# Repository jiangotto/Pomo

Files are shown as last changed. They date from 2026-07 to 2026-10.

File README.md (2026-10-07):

# Pomo

[English](README.md) | [简体中文](README_CN.md)

An open-source FPGA controller board that converts a 2-lane MIPI DSI video stream into source/gate timing for parallel-interface electrophoretic displays (EPDs).

## Overview

Pomo accepts ordinary RGB888 video from a Linux SBC or another MIPI DSI host and converts it into the waveform-driven pixel states and scanning signals required by a parallel-interface E-Ink display. Both generations use a Gowin GW1NSR-4C FPGA and a HyperRAM framebuffer.

## Versions

Pomo currently has two matching hardware and firmware generations:

| | V1 | V2 |
|---|---|---|
| Status | Original version, retained for existing boards | Current version and active development target |
| EPD Source bus | 8-bit, four 2-bit pixels per SDCLK | 16-bit, eight 2-bit pixels per SDCLK |
| PMIC | TPS65185 | SY7636A by default; TPS65185 selectable in firmware |
| Control pins | FPGA controls GDOE, SDOE, PMIC WAKEUP and VCOM control | GDOE/SDOE and PMIC auxiliary control are handled by hardware, freeing pins for D8–D15 |
| Project paths | `Firmware/V1`, `Hardware/V1`, `Case/V1` | `Firmware/V2`, `Hardware/V2`, `Case/V2` |

V1 and V2 bitstreams are not interchangeable because their EPD bus width, pin assignment, and PMIC control differ. Choose one generation and use its matching firmware, hardware, and mechanical files.

## V2

<div align="center">
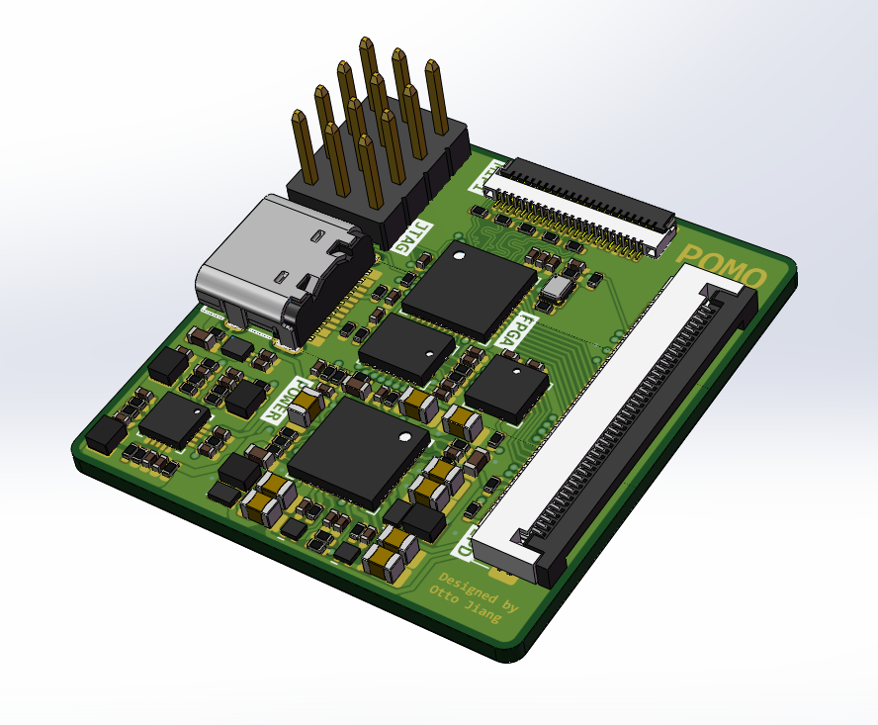
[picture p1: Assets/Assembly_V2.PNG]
Pomo V2 assembly
  
</div>

V2 combines the FPGA, HyperRAM, EPD power-management circuit, and 16-bit parallel Source interface on one board. It is the recommended starting point for new builds and the main focus of the documentation below.

The MIPI input has been tested with Luckfox and Waveshare development boards. Depending on the host connector, a reverse FPC cable may be required.

## V2 highlights

- 2-lane MIPI DSI RGB888 video input
- Gowin MIPI receiver configured for two lanes in 1:16 mode
- Dynamically measured MIPI byte clock and runtime PLL output-divider selection
- HyperRAM framebuffer for current and target pixel states, with optional packed 12-bit state storage
- 16-bit EPD source bus: eight 2-bit drive pixels are loaded per SDCLK
- Source and gate timing generation for parallel-interface EPD panels
- Selectable SY7636A or TPS65185 PMIC control; V2 defaults to SY7636A
- Optional `2W × H` to `W × 2H` pixel reorder for ET073TC1-style panel mappings
- Built-in static and animated test patterns that can replace the MIPI source
- Blue-noise dithering and multiple waveform/update modes
- FIFO, framebuffer and frame-level diagnostic counters
- Wider horizontal timing counters for high-resolution panels such as 1216 × 684
- Runtime display-mode switching through an in-stream MIPI DSI generic short packet
- Runtime PMIC power control with fail-safe EPD output clamping on MIPI PLL loss

The current 1216 × 684 configuration has been tested at up to 85 Hz. This result depends on a short, well-routed FPC connection and correctly tuned D-PHY input delay; it is not a guaranteed limit for every host, cable, or PCB.

## Data path

```text
2-lane MIPI DSI
      │
      ▼
Gowin D-PHY RX ──► DSI packet decode ──► RGB888 byte-to-pixel conversion
                                              │
                         optional pixel reorder / internal test source
                                              │
                                              ▼
                               grayscale + dithering + waveform engine
                                              │
                                              ▼
                                      HyperRAM framebuffer
                                              │
                                              ▼
                           16-bit Source timing + Gate timing ──► EPD
```

The firmware is derived from the [Caster EPDC design](https://gitlab.com/zephray/Glider) by Wenting Zhang. The original Spartan-6 implementation was ported to Gowin, adapted to a HyperRAM framebuffer, and extended for MIPI input and standalone panel driving.

## Hardware

V2 exposes a 16-bit EPD data bus together with `SDCLK`, `SDLE`, `SDCE`, `GDCLK`, and `GDSP`. `GDOE` and `SDOE` are handled by pull-ups on the V2 board rather than FPGA pins. PMIC WAKEUP/VCOM control is likewise handled by the V2 hardware, leaving FPGA pins available for `EPD_D8` through `EPD_D15`.

The Altium source, schematic PDF, PCB layout, BOM, and pick-and-place files are in [`Hardware/V2`](Hardware/V2). Do not use V1 firmware on V2 hardware or V2 firmware on V1 hardware: their EPD bus width, pin assignment, and PMIC control differ.

### JTAG / I/O header

<div align="center">
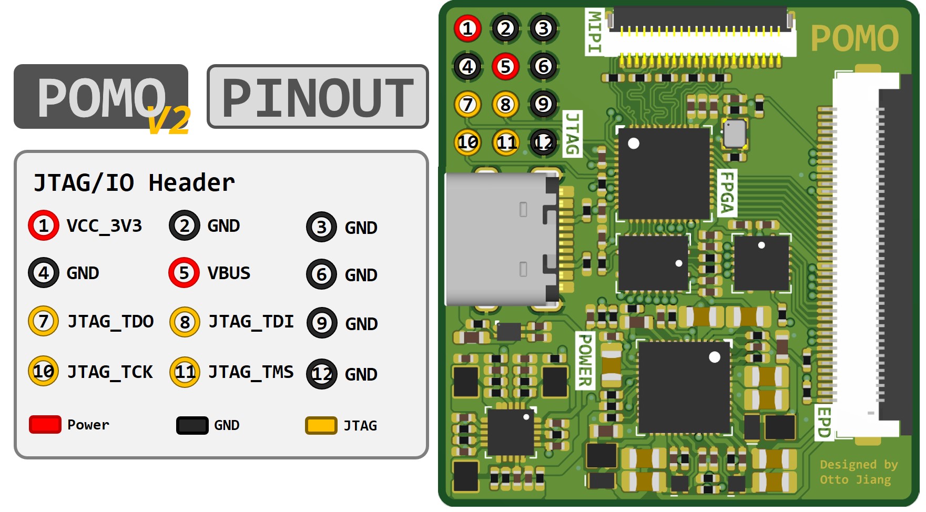
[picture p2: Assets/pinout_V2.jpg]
Pomo V2 JTAG and I/O header pinout
  
</div>

The header provides 3.3 V, VBUS, ground, and the four JTAG signals. Check orientation against the pin-1 marker before connecting a programmer.

## Example

<div align="center">
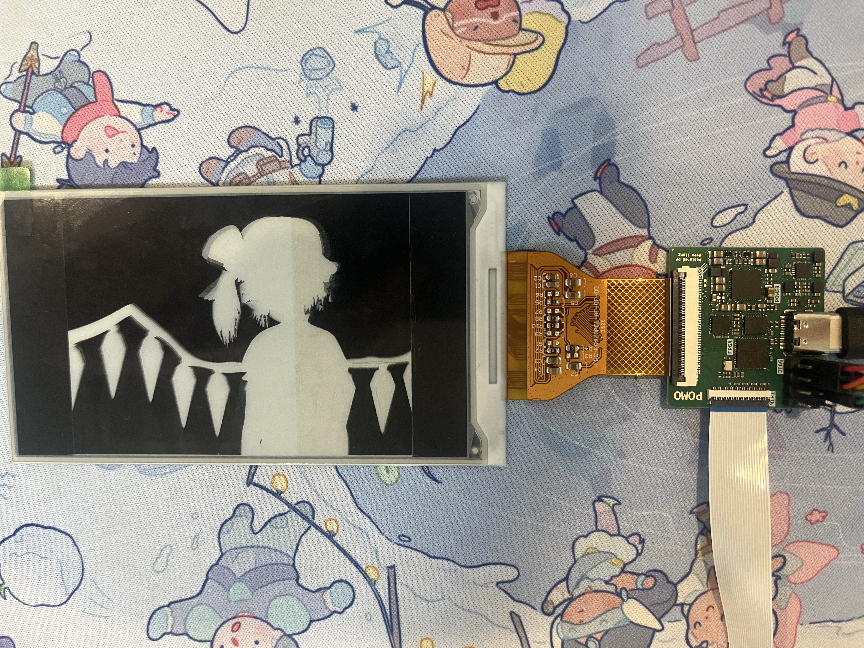
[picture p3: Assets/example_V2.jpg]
Pomo V2 driving a parallel-interface E-Ink display
  
</div>

<div align="center">
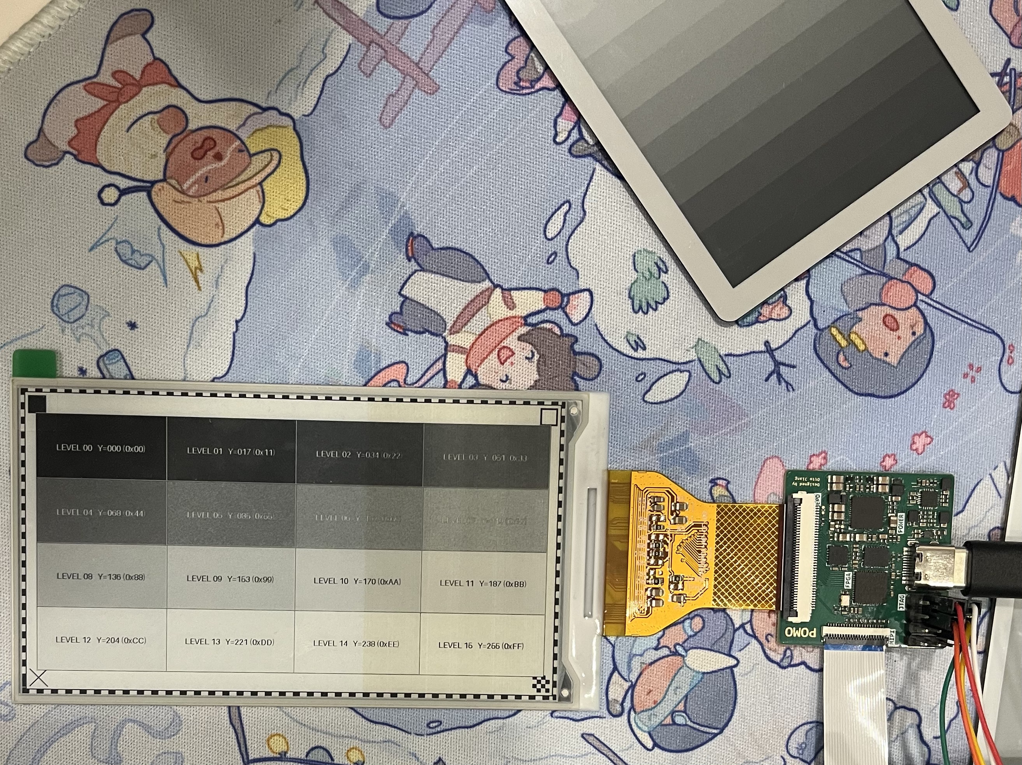
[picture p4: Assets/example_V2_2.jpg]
Pomo V2 displaying a 16-level grayscale test pattern
  
</div>

## Building the V2 firmware

1. Open [`Firmware/V2/Pomo.gprj`](Firmware/V2/Pomo.gprj) in Gowin EDA V1.9.12.
2. Edit [`Firmware/V2/src/defines.vh`](Firmware/V2/src/defines.vh) for the target PMIC, panel timing, source width, waveform mode, and VCOM voltage.
3. Verify that both generated MIPI IPs use two lanes and the same **1:16** D-PHY mode. The checked-in receiver configuration uses byte/lane alignment and an input delay of 46 on both data lanes; retune this value for the actual board and cable.
4. Run **Synthesis → Place & Route → Generate Bitstream** and confirm that both setup and hold timing pass.
5. Program the FPGA through the JTAG header.

The checked-in project uses Gowin-generated MIPI D-PHY, protocol-decoder, PLL, framebuffer and FIFO modules. The generated IP configuration and source under `Firmware/V2/src` are tracked because regenerating an IP with different GUI settings changes hardware behavior. Disposable synthesis, simulation and implementation products are excluded from version control.

## V2 firmware configuration

The main build-time switches are defined in [`Firmware/V2/src/defines.vh`](Firmware/V2/src/defines.vh):

| Option | Purpose |
|---|---|
| `PMIC_SY7636A` | Keep defined for SY7636A; comment it out for TPS65185 |
| `EPD_OUTPUT_WIDTH` | Select the EPD source output width; V2 hardware uses 16 |
| `EPD_INTERNAL_TEST` | Replace the external MIPI stream with the internal video generator |
| `EPD_TEST_PATTERN_MODE` | Select one of the static or animated internal test patterns |
| `EPD_TEST_PATTERN_FPS` | Set the frame rate of the internal test source |
| `EPD_PIXEL_REORDER` | Convert a logical `2W × H` input into a physical `W × 2H` panel raster |
| `EPD_DEFAULT_MODE` | Select the power-on display mode: `8` MONO, `A` MONO + blue noise, `B` GREY, or `C` AUTO LUT |
| `EPD_STATE_12BIT` | Pack four 12-bit pixel states into three 16-bit VFB samples, reducing framebuffer traffic by 25% compared with one 16-bit state per pixel |
| `DEFAULT_*` | Set the expected MIPI active area, sync and porch timing |
| `EPD_STV_TO_G1_CKV` | Set the panel-specific CKV shift distance from STV sampling through the shift immediately before G1 |
| `VCOM_VOL` | Set panel VCOM in millivolts; always verify against the panel datasheet |
| `CLEAR_FRAMES` | Set the final zero-based index of the startup clear sequence |
| `LUT_FRAMES` | Set the waveform LUT length |

The current example configuration uses a 1216 × 684 MIPI input, 16-bit source output, packed 12-bit framebuffer states, SY7636A, MONO startup mode, and pixel reorder disabled. The internal test source runs at 85 Hz. This is an example for the panel currently under development, not a universal setting.

#### Why `EPD_STATE_12BIT` exists

This option changes only the representation stored through the framebuffer; it does **not** change the RGB888 MIPI input into 12-bit color, reduce the EPD output bus width, or reduce the available display modes or grayscale levels.

The processing pipeline's original 16-bit per-pixel state contains a 4-bit display-mode field plus 12 bits of actual per-pixel state. Because the display mode is global and identical for every pixel, repeatedly storing that upper nibble wastes HyperRAM bandwidth. With `EPD_STATE_12BIT` enabled, Pomo removes the repeated mode nibble, packs four 12-bit states into three samples of the existing 16-bit VFB, and restores the current global mode after reading:

```text
original storage: 4 pixels × 16 bits = 64 bits
packed storage:   4 pixels × 12 bits = 48 bits
```

This reduces both framebuffer write and read traffic from 2 bytes to 1.5 bytes per pixel—a 25% reduction—which provides the memory-bandwidth margin needed for high input refresh rates such as the currently tested 85 Hz mode.

- Leave `EPD_STATE_12BIT` defined for the bandwidth-optimized path.
- Comment it out to use the original one-16-bit-state-per-pixel path for comparison, debugging, or an incompatible raster width.
- The framebuffer-side active width (`EPD_HACT` after optional pixel reorder) must be divisible by four, because packing restarts at every line and each group contains four pixels. The current width of 1216 satisfies this requirement. With `EPD_PIXEL_REORDER`, the resulting physical width—not only `DEFAULT_HACT`—must satisfy it.
- No 24-bit VFB IP is required; the optimization deliberately retains the proven 16-bit VFB configuration.

### MIPI receiver configuration and signal integrity

The two generated MIPI IPs must use matching settings:

- **MIPI RX Advance:** two data lanes, 1:16 D-PHY mode, byte alignment enabled, lane alignment enabled.
- **MIPI DSI/CSI-2 Receiver:** DSI interface, two RX lanes, 1:16 D-PHY mode, I/O insertion disabled.

At high lane rates, a syntactically correct design may still show split frames, snow, or corrupted pixels when the sampling eye is too narrow. Use the shortest practical FPC, keep both lanes well matched, and tune `HS Data0/1 IO Delay Value` using repeatable test images. The current value of 46 is a result for the tested Pomo/RK3506 connection, not a panel parameter. This GW1NSR-4C configuration does not perform automatic IODELAY training, so a different host, PCB, or cable may require a new value.

For RGB888 in 1:16 D-PHY mode, with `L` active data lanes:

```text
pixel clock     = H_TOTAL × V_TOTAL × refresh rate
1:16 word clock = pixel clock × 3 / (2 × L)
D-PHY clock     = pixel clock × 12 / L
```

Set `MIPI_RX_LANES` in `defines.vh` and enable the matching `Pomo_1lane.sdc` or `Pomo_2lane.sdc` in `Firmware/V2/Pomo.gprj`. The checked-in project defaults to two lanes. When changing resolution or maximum refresh rate, update that lane's clock constraints along with the video timing. Do not hide failures by removing the HS, word, pixel, or HyperRAM constraints. The 4-lane implementation and its disabled SDC are retained for development, but 4-lane is not a supported build: hardware validation has failed and the current implementation nearly exhausts FPGA resources.

### Runtime display and power control

The display mode and panel power request can be changed without rebuilding the FPGA by sending a MIPI DSI **Generic Short Write, 2 parameters** packet (`DT = 0x23`):

| Payload | Mode |
|---|---|
| `50 08` | MONO |
| `50 0A` | MONO + blue noise |
| `50 0B` | GREY |
| `50 0C` | AUTO LUT |
| `51 00` | Clamp the EPD interface and place the PMIC in standby |
| `51 01` | Request panel power-on; the normal initialization clear runs again |
| `52 A5` | Restart the initialization clear without cycling panel power, then return to the requested display mode |

With a Rockchip `panel-simple-dsi` driver that supports the `panel-init-sequence` format, the startup mode can be selected in the panel device-tree node. For example, this sequence has been verified to select AUTO LUT before video begins:

```dts
panel-init-sequence = [
    23 0A 02 50 0C
];
```

`23` is the DSI data type for Generic Short Write with two parameters, `0A` is a 10 ms delay after transmission, `02` is the payload length, and `50 0C` is Pomo's display-mode command. Startup commands are received over LPDT, so they do not have to wait for HS video or IODELAY training. To select another mode, replace the final byte with `08`, `0A`, or `0B` from the table above. `EPD_DEFAULT_MODE` remains the fallback when no mode command is received. Other hosts or panel drivers may use a different device-tree command format; do not assume this five-byte wrapper is universal.

During active video, insert commands as HS short packets while the DSI controller remains in video mode. Do **not** switch the DesignWare DSI host's `MODE_CFG` to command mode and back: doing so restarts the video packetizer at an arbitrary horizontal phase and can shift the image. A Linux kernel panel/bridge driver should normally issue the packet through `mipi_dsi_generic_write()`. If a diagnostic register-level tool is used, it must leave `MODE_CFG`, `VID_MODE_CFG`, and the running video timing unchanged and only enqueue the HS short packet through the generic-command FIFO.

The power request defaults to ON, but in the normal MIPI build the physical panel rails remain off until the dynamically configured pixel PLL is ready and locked. `51 00` first clamps the complete EPD interface to its inactive levels, then places the selected PMIC in standby. For SY7636A this clears `ON_OFF` while keeping `EN` high so I2C remains available; for TPS65185 it lowers `PWRUP`. After `51 01`, Pomo waits for the PMIC and HyperRAM, returns to `INIT_IDLE`, and performs `INIT_CLEARING` before normal updates resume. `EPD_INTERNAL_TEST` does not require a MIPI lock and powers the PMIC from the internal test path.

`52 A5` leaves the PMIC and MIPI receiver running. It returns the panel state machine to `INIT_IDLE`, starts `INIT_CLEARING` on the next clean frame boundary, and preserves the currently requested display mode. The fixed `A5` key reduces the chance that an unrelated short packet accidentally requests a full clear.

### Determining the MIPI scan timing

The `DEFAULT_H*` and `DEFAULT_V*` values describe the video timing received over MIPI DSI. They must match the mode generated by the host exactly; they are not copied from the EPD gate-driver blanking requirements.

1. Open the [Video Timings Calculator](https://tomverbeure.github.io/video_timings_calculator).
2. Enter the logical MIPI image width under **Horizontal Pixels**, the logical image height under **Vertical Pixels**, and the required frame rate under **Refresh Rate (Hz)**. Use progressive scan with margins disabled unless the host has a specific requirement otherwise.
3. In the results table, use the values from the **CVT-RBv2** column. Do not mix values from the CVT, CVT-RB, CEA-861, or DMT columns.
4. Copy the CVT-RBv2 results into `Firmware/V2/src/defines.vh` using this mapping:

| CVT-RBv2 result | Pomo setting | Unit |
|---|---|---|
| H Active | `DEFAULT_HACT` | pixels |
| H Front Porch | `DEFAULT_HFP` | pixels |
| H Sync | `DEFAULT_HSYNC` | pixels |
| H Back Porch | `DEFAULT_HBP` | pixels |
| V Active | `DEFAULT_VACT` | lines |
| V Front Porch | `DEFAULT_VFP` | lines |
| V Sync | `DEFAULT_VSYNC` | lines |
| V Back Porch | `DEFAULT_VBP` | lines |
| Pixel Clock | host display timing | MHz; convert to Hz if required by the host |

5. Configure the Linux MIPI DSI panel/display mode with the same active area, porches, sync widths, and pixel clock. A typical device-tree timing block has the following shape; the containing node and polarity properties depend on the host display driver:

```dts
display-timings {
    native-mode = <&timing0>;

    timing0: timing0 {
        clock-frequency = <PIXEL_CLOCK_HZ>;
        hactive = <H_ACTIVE>;
        hfront-porch = <H_FRONT_PORCH>;
        hsync-len = <H_SYNC>;
        hback-porch = <H_BACK_PORCH>;
        vactive = <V_ACTIVE>;
        vfront-porch = <V_FRONT_PORCH>;
        vsync-len = <V_SYNC>;
        vback-porch = <V_BACK_PORCH>;
    };
};
```

6. Check the copied values before building:

```text
H_TOTAL = DEFAULT_HACT + DEFAULT_HFP + DEFAULT_HSYNC + DEFAULT_HBP
V_TOTAL = DEFAULT_VACT + DEFAULT_VFP + DEFAULT_VSYNC + DEFAULT_VBP
refresh rate = pixel clock / (H_TOTAL × V_TOTAL)
```

The calculated refresh rate should match the requested rate apart from normal rounding. Whenever the resolution or refresh rate changes, generate a new complete CVT-RBv2 mode and update both the host and Pomo; changing only the pixel clock or only one porch can make the reconstructed MIPI scan position disagree with the incoming packets.

`EPD_STV_TO_G1_CKV` is separate from the CVT-RBv2 video timing. It describes the number of panel CKV shifts from sampling STV through the shift immediately before G1 is selected. Obtain it from the panel or gate-driver timing specification and do not derive it from the MIPI `VFP`, `VSYNC`, or `VBP` values.

When `EPD_PIXEL_REORDER` is enabled, enter the logical host-visible MIPI resolution in the calculator and in `DEFAULT_HACT`/`DEFAULT_VACT`. The physical EPD resolution is produced by the reorder logic and must not be used as the calculator input.

### Pixel reorder

Some long-strip panels expose a physical raster different from the host-visible video raster. When `EPD_PIXEL_REORDER` is enabled, Pomo applies:

```text
physical(x, 2y)     = logical(2x,     y)
physical(x, 2y + 1) = logical(2x + 1, y)
```

For example, a 750 × 200 MIPI image becomes a 375 × 400 physical EPD image. Reorder mode requires an even input width, an even horizontal total, and a vertical front porch of at least one line. Horizontal padding is applied when the reordered source line does not fill the final output word.

### Internal test source

Define `EPD_INTERNAL_TEST` to test a panel without a running MIPI source. The generated video still passes through the normal reorder, dithering, waveform, framebuffer, and EPD timing pipeline. Available patterns include grayscale steps, bars, checkerboards, and moving regions for checking 16-level grayscale and dynamic update behavior.

### Panel safety

Parallel-interface EPD panels require the correct waveform LUT, VCOM setting, supply sequence, and output-enable behavior. A mismatched resolution or malformed input stream can otherwise clock unintended data into areas outside the valid image. FIFO, framebuffer, and frame fault signals are diagnostics; they do not by themselves make an arbitrary malformed stream safe.

The MIPI-derived pixel clock can stop without giving a synchronous scan state machine another edge. Pomo therefore clamps the physical interface through a single clock-independent output gate when the raw pixel-PLL `LOCK` is lost, a power-off command is received, or the PMIC/HyperRAM is not ready:

```text
GDCLK=0, GDSP=1, SDCLK=0, SDLE=0, SDCE=1, DATA=0
```

Only after the clamp is active does the PMIC enter standby and discharge its rails. On recovery the clamp remains active until the supplies and memory are ready; the video-domain reset then causes the next valid frame to start from the initialization clear sequence.

**Do not validate sudden MIPI removal on a valuable panel first.** With the panel disconnected, use an oscilloscope to verify that the specific generated bitstream drives all six groups above to their safe levels immediately when the MIPI clock is removed, and that this happens before `VPOS`, `VNEG`, and `VCOM` discharge. The protection depends on the Gowin PLL actually deasserting `LOCK` when its input clock disappears. If a host keeps the DSI clock lane running while it stops video packets, PLL-loss protection cannot detect that condition; send `51 00` before intentionally stopping such a source.

## Repository layout

```text
Pomo_DriverBoard/
├── Firmware/
│   ├── V2/                    Current 16-bit Gowin firmware
│   └── V1/                    Original 8-bit firmware archive
├── Hardware/
│   ├── V2/                    Current Altium design and manufacturing files
│   └── V1/                    Original hardware archive
├── Case/
│   ├── V2/                    Current enclosure/model assets
│   └── V1/                    Original enclosure/model archive
├── Assets/                    README images
└── LICENSE                    CERN-OHL-S v2
```

## V1 compatibility

V1 is preserved under [`Firmware/V1`](Firmware/V1), [`Hardware/V1`](Hardware/V1), and [`Case/V1`](Case/V1). Open `Firmware/V1/Pomo.gprj` when building for the original 8-bit board. V1 and V2 bitstreams are not interchangeable.

## License

Pomo hardware and firmware are licensed under the **CERN Open Hardware Licence Version 2 – Strongly Reciprocal (CERN-OHL-S v2)**. See [LICENSE](LICENSE).

Portions derived from Caster remain under CERN-OHL-P v2; see [`Firmware/V2/LICENSE-CERN-OHL-P`](Firmware/V2/LICENSE-CERN-OHL-P).

## Acknowledgments

- [Wenting Zhang](https://gitlab.com/zephray) — original Caster EPDC design
- [CERN](https://cern.ch/cern-ohl) — CERN Open Hardware Licence

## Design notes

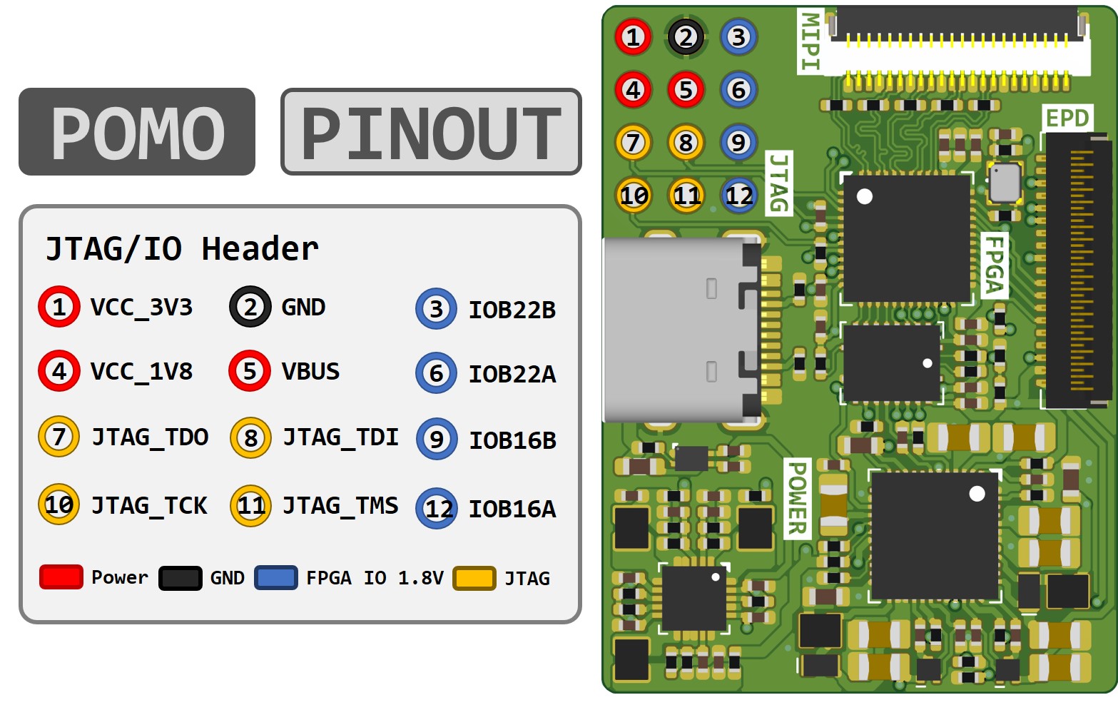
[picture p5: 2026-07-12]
Assets/pinout.jpg

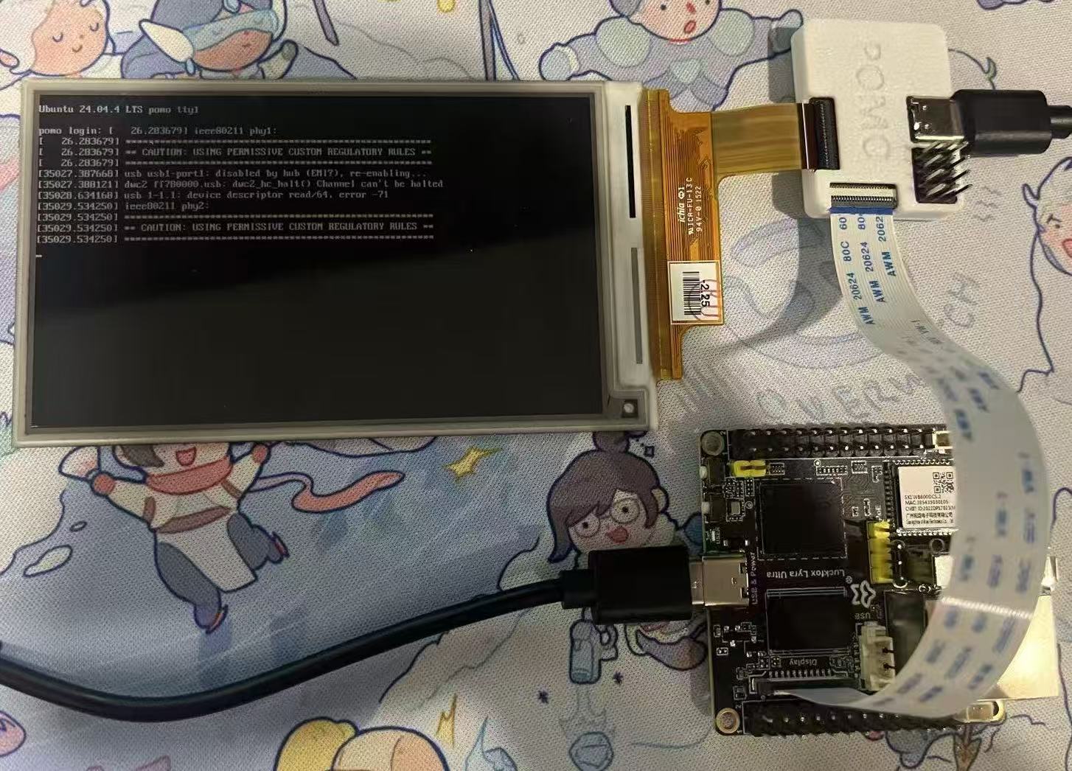
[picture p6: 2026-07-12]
Assets/example.jpg

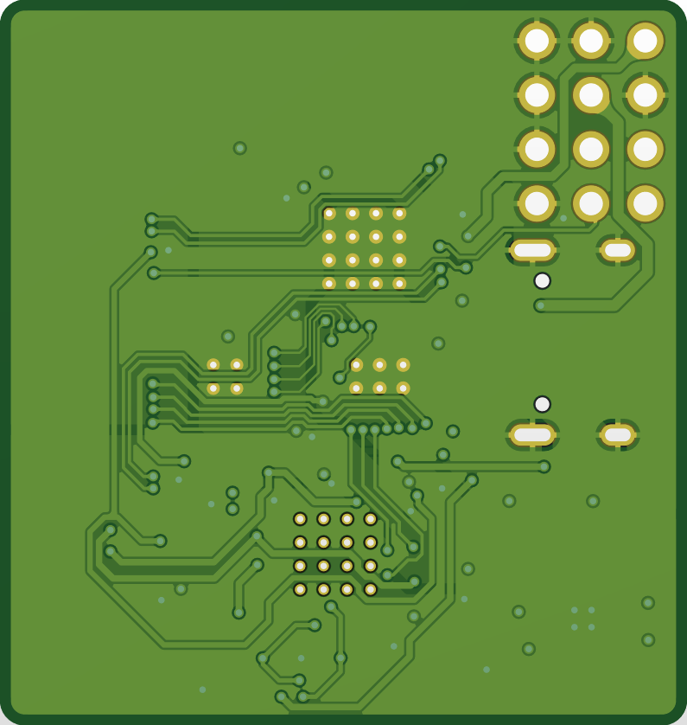
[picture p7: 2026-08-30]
Case/V2/BOTTOM.PNG

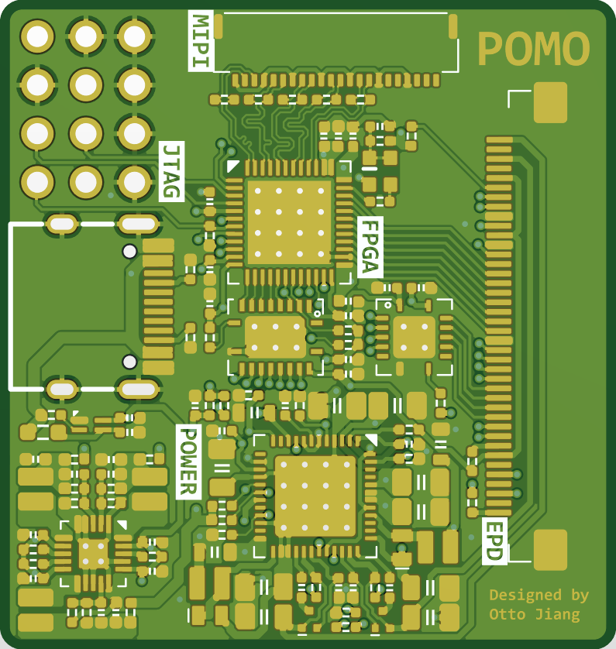
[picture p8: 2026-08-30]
Case/V2/TOP.PNG

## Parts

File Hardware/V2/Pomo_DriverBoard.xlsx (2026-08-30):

Comment | Description | Designator | Footprint | LibRef | Quantity
4.7uF | CL05A475MO5NUNC | C1, C6, C12, C36, C38 | Capacitor-0402 | Capacitor-0402 | 5
4.7uF | CL21A475KBQNNNE | C2, C3, C4, C7, C9, C10, C14, C18, C19 | Capacitor-0805 | Capacitor-0805 | 9
10uF | CL10A106KP8NNNC | C5, C8, C17 | Capacitor-0603 | Capacitor-0603 | 3
47nF | CC0402KRX7R9BB473 | C11, C16 | Capacitor-0402 | Capacitor-0402 | 2
100nF | CL05B104KB5NNNC | C32, C33, C34, C35, C37, C39, C40, C41, C42, C43, C44 | Capacitor-0402 | Capacitor-0402 | 11
10uF | HGC0402R5106M100NTEJ | C20, C21, C22, C25, C26, C27, C28, C30 | Capacitor-0402 | Capacitor-0402 | 8
220pF | CL05C221JB5NNNC | C23, C29, C31 | Capacitor-0402 | Capacitor-0402 | 3
1uF | HGC0402R5105K500NTEJ | C13, C15, C24 | Capacitor-0402 | Capacitor-0402 | 3
MS2A40LDF | MS2A40LDF | D1, D4 | MS2A40LDF-DFN-2_1.6x1.0mm | MS2A40LDF | 2
BAV99QA | BAV99QA/1SS362FV | D2, D3 | BAV99QA-DFN-3_1.1x1.0mm | BAV99QA | 2
600Ω@100MHz | UPZ1608U601-1R3TF | FB1 | Ferrite Bead-0603 | Ferrite Bead-0603 | 1
120Ω@100MHz | UPZ1005D121-1R3TF | FB2, FB3, FB4, FB5 | Ferrite Bead-0402 | Ferrite Bead-0402 | 4
FPC-22P-0.5mm | HC-FPC-05-10-22RLTAG | J1 | HC-FPC-05-10-22RLTAG | FPC-22P-0.5mm | 1
E0470A01-AF-S | AFC01-S40FCA-00 | J2 | E0470A01-AF-S | E0470A01-AF-S | 1
CONN_HDR_3X4_2.54mm | HX PZ2.54-3x4P ZZ | J3 | CONN_HDR_3X4_2.54mm | CONN_HDR_3X4_2.54mm | 1
2.2uH | FTC201612S2R2MBCA | L1 | Inductor-2016 | Inductor-2016 | 0
4.7uH | FTC201610S4R7MBCA | L1, L2 | Inductor-2016 | Inductor-2016 | 2
1.5uH | FTC201610S1R5MBCA | L3, L4, L5 | Inductor-2016 | Inductor-2016 | 3
10K | Resistor-0402 | R1, R32, R33, R34, R37 | Resistor-0402 | Resistor-0402 | 5
43.2K | Resistor-0402 | R2 | Resistor-0402 | Resistor-0402 | 1
5.1M | Resistor-0402 | R3, R4, R11 | Resistor-0402 | Resistor-0402 | 3
4.7K/NC | Resistor-0402 | R5, R8, R35, R36 | Resistor-0402 | Resistor-0402 | 4
1M | Resistor-0402 | R6, R9 | Resistor-0402 | Resistor-0402 | 2
47.5K | Resistor-0402 | R7 | Resistor-0402 | Resistor-0402 | 1
52.3K | Resistor-0402 | R10 | Resistor-0402 | Resistor-0402 | 1
5.1K | Resistor-0402 | R12, R13 | Resistor-0402 | Resistor-0402 | 2
100K | Resistor-0402 | R14, R18, R19, R21 | Resistor-0402 | Resistor-0402 | 4
68K 1% | Resistor-0402 | R15 | Resistor-0402 | Resistor-0402 | 1
15K 1% | Resistor-0402 | R16 | Resistor-0402 | Resistor-0402 | 1
100K 1% | Resistor-0402 | R17, R20, R25 | Resistor-0402 | Resistor-0402 | 3
200K 1% | Resistor-0402 | R22 | Resistor-0402 | Resistor-0402 | 1
100R | Resistor-0402 | R23, R24, R26, R27, R28 | Resistor-0402 | Resistor-0402 | 5
4.7K | Resistor-0402 | R29 | Resistor-0402 | Resistor-0402 | 1
49.9R | Resistor-0402 | R30 | Resistor-0402 | Resistor-0402 | 1
0R/NC | Resistor-0402 | R31 | Resistor-0402 | Resistor-0402 | 1
TPS65185 | TPS65185/SY7636A | U1 | TPS65185-VQFN-48_6x6mm | TPS65185 | 1
SY6283ADRC | SY6283ADRC | U2 | SY6283ADRC-dfn-4_1.2x1.6mm | SY6283ADRC | 1
EA3036CQBR | EA3036CQBR | U3 | EA3036-QFN-20 | EA3036CQBR | 1
GW1NSR-LV4CQN48PC7/I6 | GW1NSR-LV4CQN48PC7/I6 | U4 | GW1NSR-LV4CQN48P-QFN-48_6X6 | GW1NSR-LV4CQN48P | 1
TXS0108ERGYR | TXS0108ERGYR | U5 | TXS0108E-VQFN-20-3.5x4.5mm | TXS0108E | 1
TXS0104ERGYR | TXS0104ERGYR | U6 | TXS0104E-VQFN-14-3.5x3.5mm | TXS0104E | 1
TYPE-C | GT-USB-7010ASV | USB1 | TYPE-C-16P | TYPE-C | 1
27MHz | OC7EL89CJO-113YLC-27M | X1 | Oscillator-2016 | Oscillator_Source-2016 | 1

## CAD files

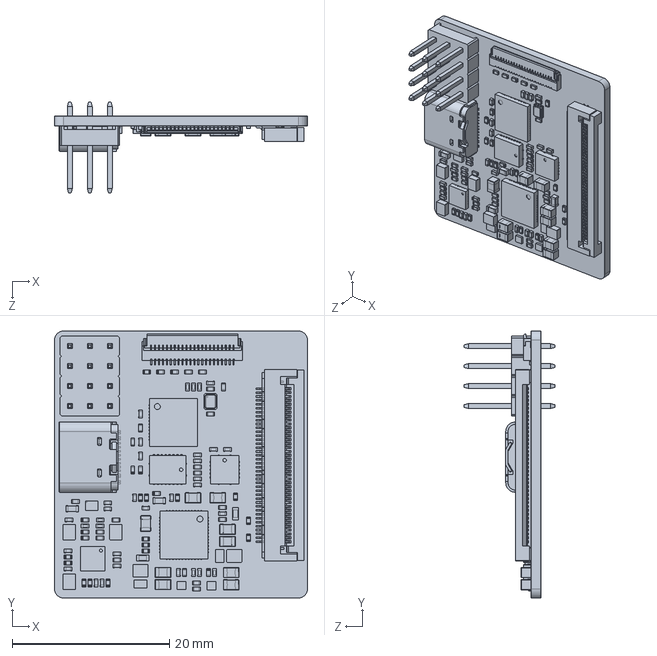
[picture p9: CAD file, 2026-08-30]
Case/V2/PCB_V2.SLDPRT
32.2 x 34.0 x 11.5 mm

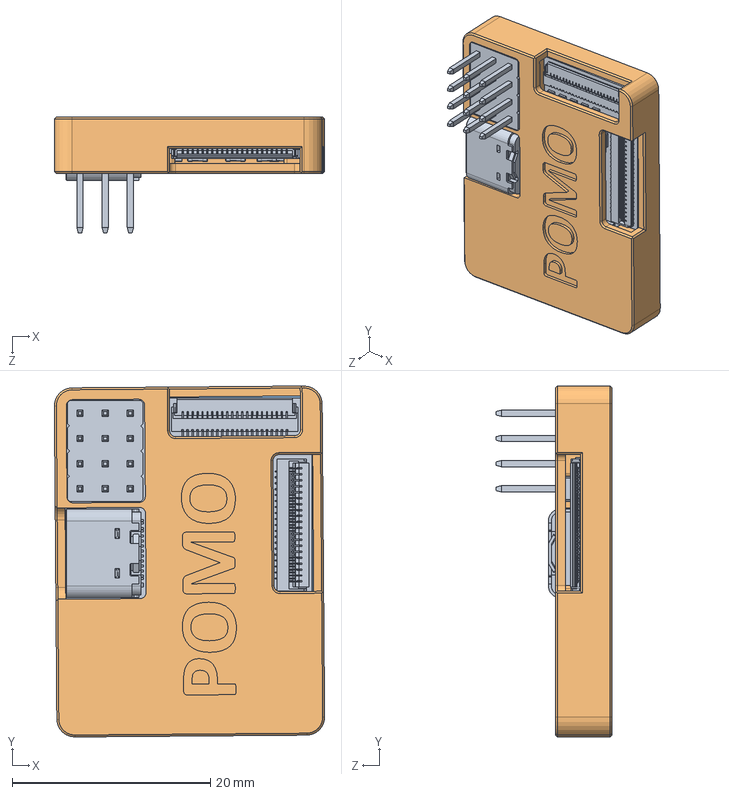
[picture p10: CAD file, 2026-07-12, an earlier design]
Case/V1/Assembly.SLDASM
27.2 x 35.4 x 11.7 mm
PCB
Case
Lid

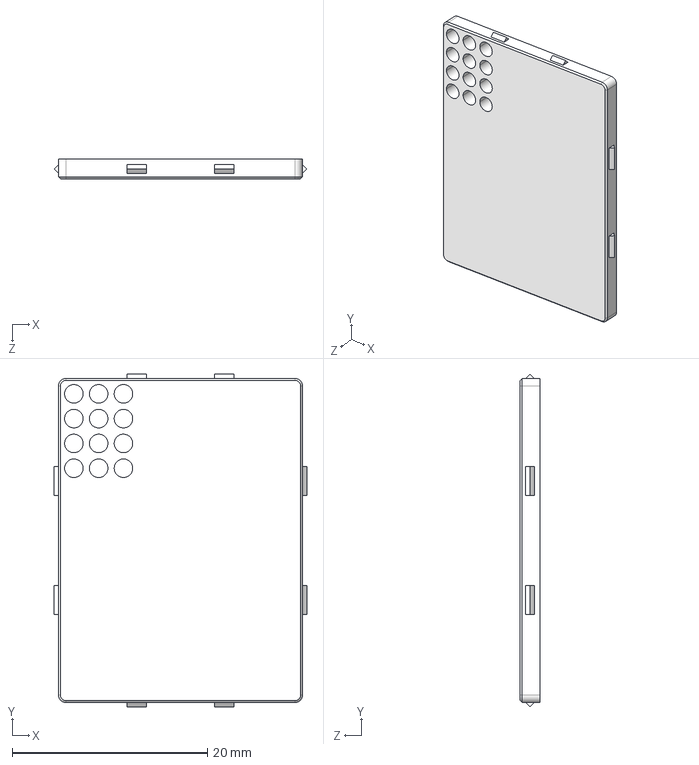
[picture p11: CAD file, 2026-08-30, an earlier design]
Case/V1/Lid.STEP
25.9 x 34.1 x 2.00 mm

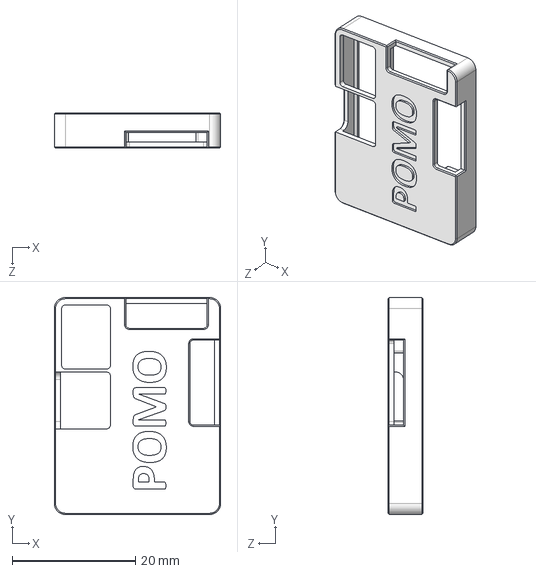
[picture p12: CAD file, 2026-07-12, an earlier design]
Case/V1/Case.STEP
27.0 x 35.2 x 5.72 mm

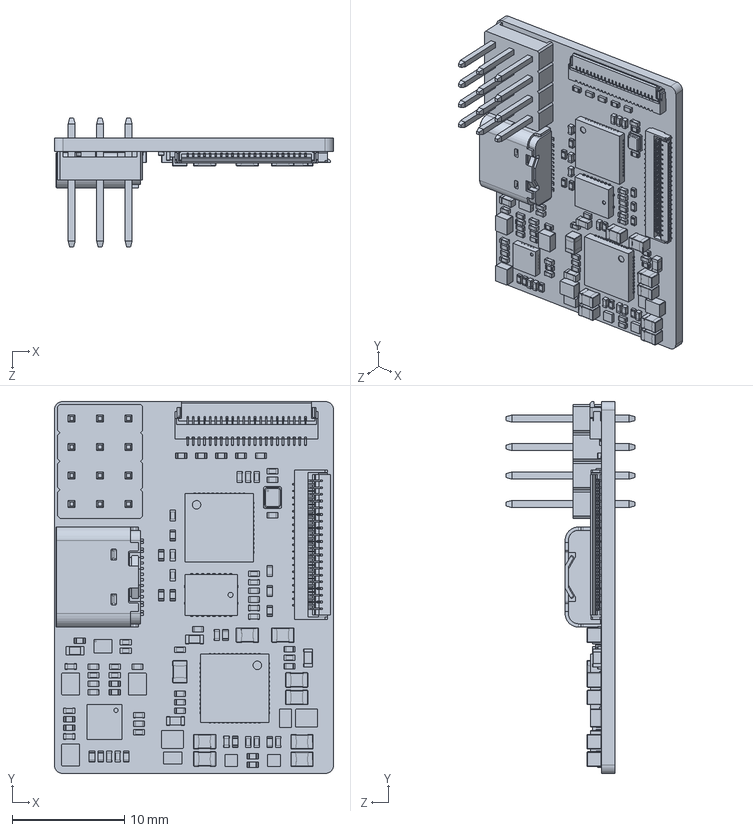
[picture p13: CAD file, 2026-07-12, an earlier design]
Case/V1/PCB.SLDPRT
24.9 x 33.2 x 11.5 mm

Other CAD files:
Case/V1/Case.3mf
Case/V1/Case.SLDPRT
Case/V1/Lid.SLDPRT

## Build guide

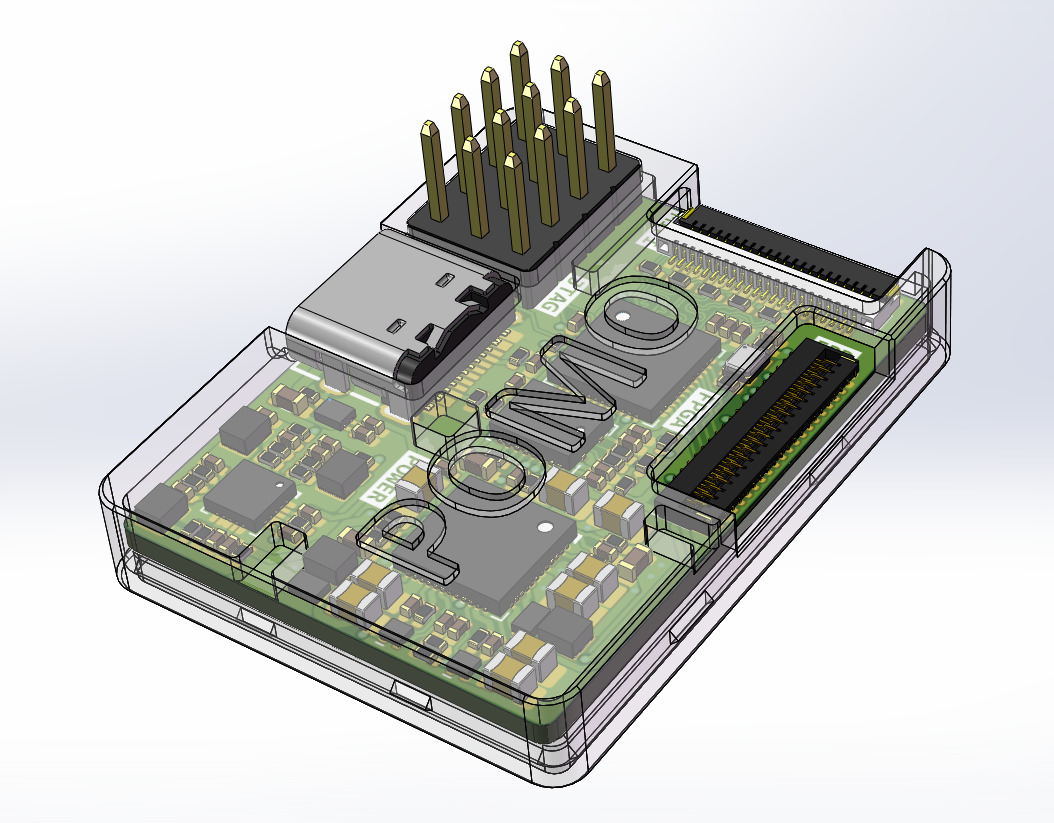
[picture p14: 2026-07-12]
Assets/Assembly.PNG

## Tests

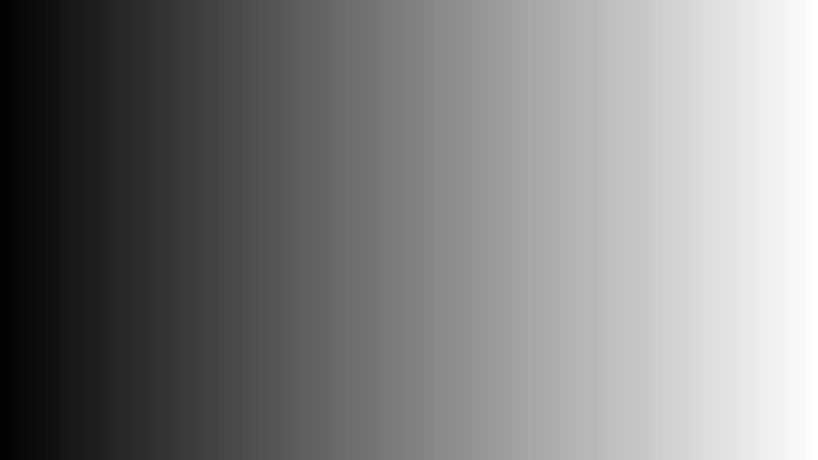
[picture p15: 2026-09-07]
Assets/TestPatterns/epd_uniform_grayscale_gradient_1216x684.png

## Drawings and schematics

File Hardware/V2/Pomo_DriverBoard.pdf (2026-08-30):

22 22 23 23 24 24

# Type-C Power Input

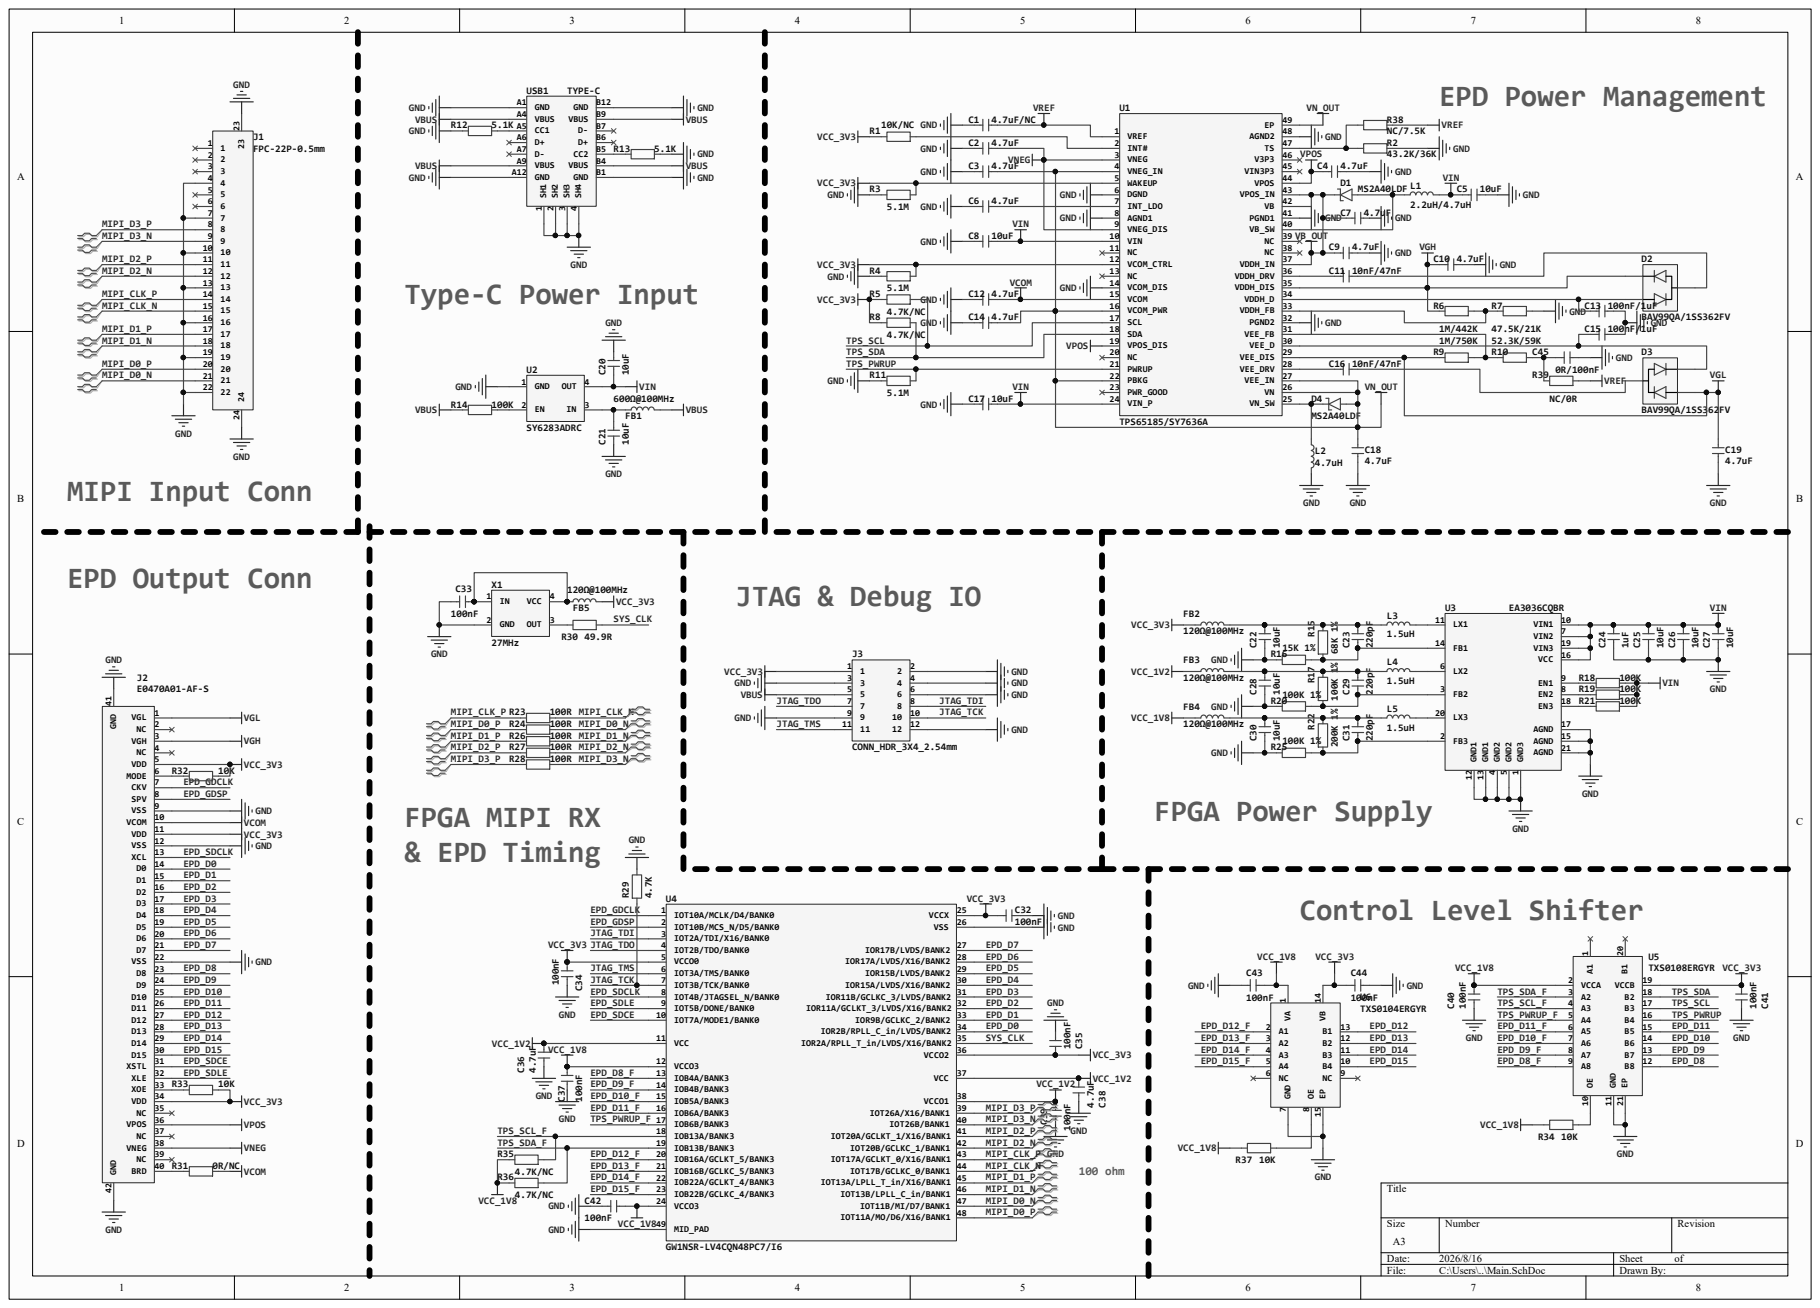
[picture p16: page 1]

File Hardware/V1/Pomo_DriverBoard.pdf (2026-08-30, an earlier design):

22 22 23 23 24 24

# Type-C Power Input

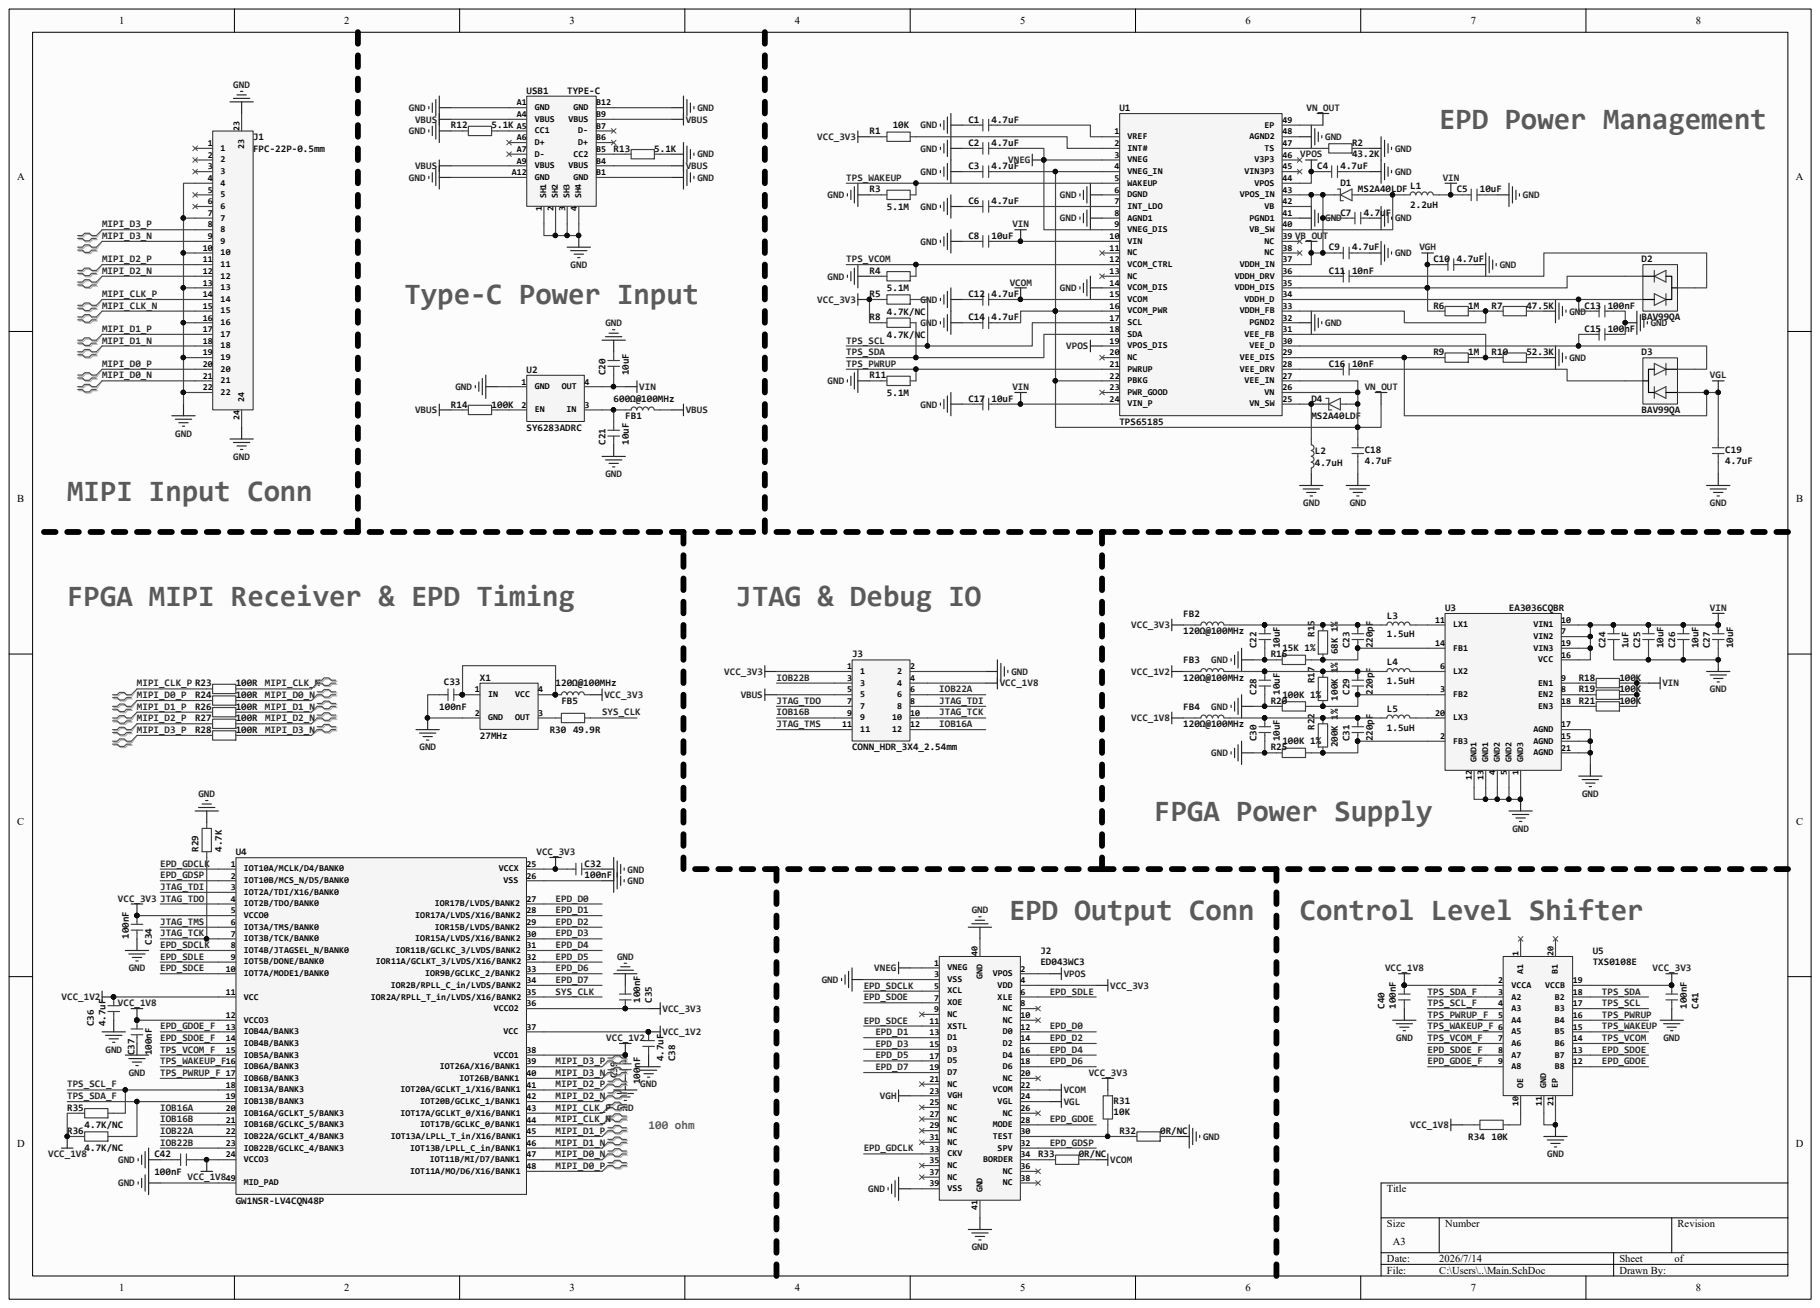
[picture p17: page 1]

FPGA MIPI Receiver & EPD Timing

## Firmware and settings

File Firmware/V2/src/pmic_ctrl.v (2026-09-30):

// Copyright Yuhan Jiang 2025-2026
//
// This source describes Open Hardware and is licensed under the CERN-OHL-S v2.

`timescale 1ns/1ps

// Unified EPD PMIC initialization controller.
// Define PMIC_SY7636A in defines.vh for SY7636A; leave it undefined for
// TPS65185. The external signal names describe the shared package pins.
module pmic_ctrl #(
	parameter integer vcom_val = 1310
) (
	input  wire clk,                 // 27 MHz
	input  wire rst_n,
	input  wire power_on,            // retained runtime request, high after reset

	output reg  pmic_pwrup,          // pin 21: TPS PWRUP / SY EN
	inout  wire pmic_sda,
	inout  wire pmic_scl,

	output reg  done_flag,
	output reg  error_flag
);

`ifdef PMIC_SY7636A
	localparam [6:0] DEV_ADDR = 7'h62;
	localparam [2:0] LAST_CONFIG = 3'd4;
`else
	localparam [6:0] DEV_ADDR = 7'h68;
	localparam [2:0] LAST_CONFIG = 3'd5;
`endif

	// Both devices retain the board's original 10 ms startup delay. SY7636A
	// additionally requires EN high for 2.5 ms before accepting I2C commands.
	localparam integer PRE_EN_CYCLES  = 270000; // 10 ms at 27 MHz
	localparam integer EN_WAIT_CYCLES =  67500; // 2.5 ms at 27 MHz
	localparam integer READY_CYCLES   = 540000; // 20 ms at 27 MHz

	reg [19:0] startup_cnt;
	reg        start;

	always @(posedge clk or negedge rst_n) begin
		if (!rst_n) begin
			startup_cnt <= 20'd0;
			start       <= 1'b0;
			pmic_pwrup  <= 1'b0;
		end else begin
`ifdef PMIC_SY7636A
			if (startup_cnt < PRE_EN_CYCLES + EN_WAIT_CYCLES) begin
				startup_cnt <= startup_cnt + 20'd1;
				if (startup_cnt >= PRE_EN_CYCLES - 1)
					pmic_pwrup <= 1'b1;
			end else begin
				pmic_pwrup <= 1'b1;
				start      <= 1'b1;
			end
`else
			if (startup_cnt < PRE_EN_CYCLES)
				startup_cnt <= startup_cnt + 20'd1;
			else
				start <= 1'b1;
			// Keep PWRUP low while programming the TPS65185. Once configured,
			// power_on directly selects ACTIVE or STANDBY.
			pmic_pwrup <= power_on && (wr_index >= 6'd12);
`endif
		end
	end

	reg         I_TX_EN;
	reg  [2:0]  I_WADDR;
	reg  [7:0]  I_WDATA;
	reg         I_RX_EN;
	reg  [2:0]  I_RADDR;
	wire [7:0]  O_RDATA;

	localparam [2:0] PRERLO = 3'b000;
	localparam [2:0] PRERHI = 3'b001;
	localparam [2:0] CTR    = 3'b010;
	localparam [2:0] TXR    = 3'b011;
	localparam [2:0] CR     = 3'b100;
	localparam [2:0] SR     = 3'b100;

	// 27 MHz / (5 * 100 kHz) - 1 = 53.
	localparam [7:0] CLK_DIV_L = 8'h35;
	localparam [7:0] CLK_DIV_H = 8'h00;
	localparam [7:0] EN_IP     = 8'h80;
	localparam [7:0] STA_WR_CR = 8'h90;
	localparam [7:0] WR_CR     = 8'h10;
	localparam [7:0] STP_WR_CR = 8'h50;
	localparam       WR        = 1'b0;

	localparam integer VCOM_RAW = vcom_val / 10;
`ifdef PMIC_SY7636A
	localparam integer VCOM_CODE = (VCOM_RAW > 500) ? 500 :
	                               ((VCOM_RAW < 0) ? 0 : VCOM_RAW);
`else
	localparam integer VCOM_CODE = (VCOM_RAW > 511) ? 511 :
	                               ((VCOM_RAW < 0) ? 0 : VCOM_RAW);
`endif

	// {register address, register data}. Six entries cover the larger TPS table.
	reg [15:0] pmic_config [0:5];
	initial begin
`ifdef PMIC_SY7636A
		pmic_config[0] = {8'h06, 8'hAA}; // 2 ms between power rails
		pmic_config[1] = {8'h03, 8'h66}; // VPOS/VNEG = +/-15.00 V
		pmic_config[2] = {8'h01, VCOM_CODE[7:0]};
		pmic_config[3] = {8'h02, {VCOM_CODE[8], 7'h14}};
		pmic_config[4] = {8'h00, 8'hC0}; // ON, external VCOM_EN, discharge enabled
		pmic_config[5] = 16'h0000;       // unused
`else
		pmic_config[0] = {8'h09, 8'hB1}; // UPSEQ0
		pmic_config[1] = {8'h0A, 8'h00}; // UPSEQ1
		pmic_config[2] = {8'h02, 8'h03}; // VADJ = +/-15 V
		pmic_config[3] = {8'h03, VCOM_CODE[7:0]};
		pmic_config[4] = {8'h04, {7'd0, VCOM_CODE[8]}};
		pmic_config[5] = {8'h01, 8'h3F}; // ENABLE
`endif
	end

	reg [5:0]  wr_index;
	reg [1:0]  wr_reg;
	reg [1:0]  rd_reg0;
	reg [2:0]  reg_addr;
	reg [7:0]  reg_data;
	reg [7:0]  sr_data0;
	reg [2:0]  config_cnt;
	reg [19:0] ready_cnt;

	always @(*) begin
		case (wr_index)
			6'd0:  begin reg_addr = PRERLO; reg_data = CLK_DIV_L; end
			6'd1:  begin reg_addr = PRERHI; reg_data = CLK_DIV_H; end
			6'd2:  begin reg_addr = CTR;    reg_data = EN_IP; end
			6'd3:  begin reg_addr = TXR;    reg_data = {DEV_ADDR, WR}; end
			6'd4:  begin reg_addr = CR;     reg_data = STA_WR_CR; end
			6'd5:  begin reg_addr = SR;     reg_data = 8'h00; end
			6'd6:  begin reg_addr = TXR;    reg_data = pmic_config[config_cnt][15:8]; end
			6'd7:  begin reg_addr = CR;     reg_data = WR_CR; end
			6'd8:  begin reg_addr = SR;     reg_data = 8'h00; end
			6'd9:  begin
				reg_addr = TXR;
`ifdef PMIC_SY7636A
				// Keep EN high in STANDBY. Clearing ON_OFF starts the PMIC's
				// specified power-down and active-discharge sequence.
				reg_data = ((config_cnt == LAST_CONFIG) && !power_on) ?
					8'h40 : pmic_config[config_cnt][7:0];
`else
				reg_data = pmic_config[config_cnt][7:0];
`endif
			end
			6'd10: begin reg_addr = CR;     reg_data = STP_WR_CR; end
			6'd11: begin reg_addr = SR;     reg_data = 8'h00; end
			default: begin reg_addr = 3'd0; reg_data = 8'h00; end
		endcase
	end
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

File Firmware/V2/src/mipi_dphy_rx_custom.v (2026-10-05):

// Copyright Yuhan Jiang 2025-2026
//
// This source describes Open Hardware and is licensed under the CERN-OHL-S v2.
//
// Parameterizable Gowin MIPI D-PHY receive front end.  This module intentionally
// contains only the physical receive and D-PHY SoT/lane alignment layers; DSI
// packet decoding belongs in the protocol layer above it.
//
// The implementation is currently for the 1:16 D-PHY mode used by Pomo.  LANES
// may be 1, 2, or 4.  Each lane finds the D-PHY SoT sync byte (8'hB8) from the
// serial bit stream and writes subsequent 16-bit words into a small elastic
// FIFO.  A word is released only when every enabled lane has one available, so
// lane skew is removed without a lane-specific fixed-cycle correction.

`timescale 1ns / 1ps

module mipi_dphy_rx_custom #(
	parameter integer LANES     = 2,
	parameter integer AUTO_TRAIN = 1,
	parameter integer IO_DELAY0 = 0,
	parameter integer IO_DELAY1 = 0,
	parameter integer IO_DELAY2 = 0,
	parameter integer IO_DELAY3 = 0
) (
	input  wire                    reset_n,

	inout  wire                    mipi_clk_p,
	inout  wire                    mipi_clk_n,
	inout  wire [LANES-1:0]        mipi_data_p,
	inout  wire [LANES-1:0]        mipi_data_n,

	input  wire [1:0]              lp_clk_in,
	input  wire                    lp_clk_dir,
	output wire [1:0]              lp_clk_out,
	input  wire [LANES*2-1:0]      lp_data_in,
	input  wire [LANES-1:0]        lp_data_dir,
	output wire [LANES*2-1:0]      lp_data_out,

	input  wire                    hs_en,
	input  wire                    clk_term_en,
	input  wire                    data_term_en,
	input  wire                    train_packet_done,
	input  wire                    train_packet_good,

	output wire                    clk_word,
	output wire [LANES*16-1:0]     data_out,
	output wire                    ready,
	output wire                    trained,
	output wire                    train_failed
);

	wire hs_clk;
	wire hs_clk_gated;
	wire [LANES-1:0] hs_data;
	wire [LANES*16-1:0] raw_words;
	wire [LANES-1:0] lane_locked;
	wire [LANES-1:0] lane_empty;
	wire [LANES*16-1:0] lane_words;
	wire delay_dynamic;
	wire [LANES-1:0] delay_setn;
	wire [LANES-1:0] delay_value;
	wire all_locked = &lane_locked;
	wire all_valid  = ~(|lane_empty);
	wire take_word  = hs_en && all_locked && all_valid;
	// The forwarded HS clock stops at the end of a burst.  Therefore state that
	// is local to one burst cannot wait for another clk_word edge to observe
	// hs_en=0; clear it asynchronously as soon as LP signalling ends the burst.
	wire burst_reset_n = reset_n && hs_en;
	reg [LANES*16-1:0] output_pipe0;
	reg [LANES*16-1:0] output_pipe1;

	// Gowin IO-logic simulation models resolve the device-wide reset through
	// an instance named GSR. The generated IP uses the same always-enabled
	// global-reset primitive.
	GSR GSR (.GSRI(1'b1));

	// P is bit 1 and N is bit 0, matching Gowin's generated MIPI RX port
	// convention. OEN is active low; receive-only operation therefore uses the
	// inverse of the LP direction input.
	MIPI_IBUF u_clk_ibuf (
		.I    (lp_clk_in[1]),
		.IB   (lp_clk_in[0]),
		.OEN  (~lp_clk_dir),
		.OENB (~lp_clk_dir),
		.IO   (mipi_clk_p),
		.IOB  (mipi_clk_n),
		.HSREN(hs_en && clk_term_en),
		.OL   (lp_clk_out[1]),
		.OB   (lp_clk_out[0]),
		.OH   (hs_clk)
	);

	// Reproduce the generated receiver's clean clock-start circuit.  The ring
	// advances from 0001 to its stopped state after HS clock activity begins;
	// DHCEN then admits only complete clock pulses to CLKDIV.
	reg [3:0] open_sync;
	wire open_sync_ce = ~open_sync[2];
	wire clock_stop = open_sync[1] | open_sync[0];

	always @(posedge hs_clk or negedge reset_n) begin
		if (!reset_n)
			open_sync <= 4'b0001;
		else if (open_sync_ce)
			open_sync <= {open_sync[2:0], open_sync[3]};
	end

	DHCEN u_hs_clock_enable (
		.CLKIN (hs_clk),
		.CE    (clock_stop),
		.CLKOUT(hs_clk_gated)
	);

	CLKDIV u_word_clock_divider (
		.HCLKIN(hs_clk_gated),
		.RESETN(reset_n),
		.CALIB (1'b0),
		.CLKOUT(clk_word)
	);
	defparam u_word_clock_divider.GSREN = "false";
	defparam u_word_clock_divider.DIV_MODE = "8";

	function integer lane_delay;
		input integer lane;
		begin
			case (lane)
				0: lane_delay = IO_DELAY0;
				1: lane_delay = IO_DELAY1;
				2: lane_delay = IO_DELAY2;
				3: lane_delay = IO_DELAY3;
				default: lane_delay = 0;
			endcase
		end
	endfunction

	genvar lane;
	generate
		for (lane = 0; lane < LANES; lane = lane + 1) begin : g_lane
			MIPI_IBUF u_data_ibuf (
				.I    (lp_data_in[lane*2+1]),
				.IB   (lp_data_in[lane*2]),
				.OEN  (~lp_data_dir[lane]),
				.OENB (~lp_data_dir[lane]),
				.IO   (mipi_data_p[lane]),
				.IOB  (mipi_data_n[lane]),
				.HSREN(hs_en && data_term_en),
				.OL   (lp_data_out[lane*2+1]),
				.OB   (lp_data_out[lane*2]),
				.OH   (hs_data[lane])
			);

			mipi_dphy_lane_deserializer_custom #(
				.IO_DELAY(lane_delay(lane))
			) u_deserializer (
				.reset_n (reset_n),
				.clk_fast(hs_clk_gated),
				.clk_word(clk_word),
				.hs_data (hs_data[lane]),
				.delay_dynamic(delay_dynamic),
				.delay_setn(delay_setn[lane]),
				.delay_value(delay_value[lane]),
				.raw_word(raw_words[lane*16 +: 16])
			);

			mipi_dphy_lane_aligner_custom #(
				.FIFO_DEPTH(LANES == 4 ? 3 : 2)
			) u_aligner (
				.reset_n (burst_reset_n),
				.clk_word(clk_word),
				.hs_en   (hs_en),
				.raw_word(raw_words[lane*16 +: 16]),
				.pop      (take_word),
				.locked   (lane_locked[lane]),
				.empty    (lane_empty[lane]),
				.data_out (lane_words[lane*16 +: 16])
			);
		end
	endgenerate

	// The Gowin packet receiver expects the generated IP's interface semantics:
	// ready is a persistent "SoT locked" level, not a per-word valid pulse.
	// The two registers also reproduce the aligner's observable delay between
	// ready assertion and the first word containing the sync byte.
	always @(posedge clk_word or negedge burst_reset_n) begin
		if (!burst_reset_n) begin
			output_pipe0 <= {(LANES*16){1'b0}};
			output_pipe1 <= {(LANES*16){1'b0}};
		end else if (take_word) begin
			output_pipe0 <= lane_words;
			output_pipe1 <= output_pipe0;
		end
	end

	assign data_out = output_pipe1;
	assign ready = all_locked;

	generate
		if (AUTO_TRAIN != 0) begin : g_iodelay_training
			mipi_iodelay_packet_trainer_custom #(
				.LANES(LANES),
				.FALLBACK0(IO_DELAY0), .FALLBACK1(IO_DELAY1),
				.FALLBACK2(IO_DELAY2), .FALLBACK3(IO_DELAY3)
			) u_trainer (
				.reset_n(reset_n), .clk_word(clk_word), .hs_en(hs_en),
				.link_ready(all_locked),
				.packet_done(train_packet_done),
				.packet_good(train_packet_good),
				.delay_dynamic(delay_dynamic),
				.delay_setn(delay_setn), .delay_value(delay_value),
				.trained(trained), .failed(train_failed)
			);
		end else begin : g_static_iodelay
			assign delay_dynamic = 1'b0;
			assign delay_setn = {LANES{1'b0}};
			assign delay_value = {LANES{1'b0}};
			assign trained = 1'b1;
			assign train_failed = 1'b0;
		end
	endgenerate
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

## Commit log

2026-07-12 Initial commit: Pomo DriverBoard
    [Assembly.SLDASM, Case.3mf, Case.SLDPRT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]
2026-08-30 release: add V2 hardware and 16-bit EPD firmware
    [Case.3mf, Lid.SLDPRT, Lid.STEP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]
2026-08-30 release: update V2 documentation and project assets
    [Assembly.SLDASM, Case.3mf, Case.SLDPRT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]
2026-09-02 firmware: checkpoint V2 waveform and source timing updates
    [du.csv, gc16.csv, gl16.csv]
2026-09-12 firmware: track Gowin IP metadata and fix project file references
2026-09-26 Optimize framebuffer storage with 12-bit states
2026-09-27 feat(fpga): finalize 85 Hz runtime mode switching
2026-09-27 docs: explain 12-bit framebuffer packing
2026-09-30 feat(fpga): add runtime panel power control
    [autolut.csv, b2gl16.csv, du.csv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]
2026-09-30 feat(fpga): add TCON registers and panel output clamp
2026-10-06 Add LPDT commands and frame-boundary MIPI recovery
